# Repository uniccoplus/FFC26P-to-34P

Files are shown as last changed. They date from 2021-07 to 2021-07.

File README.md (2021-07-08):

# FFC26P-to-34P
Replace Matsushita EME-216Y, EME-213K with FDD emulator

This is FFC 26P FDD I/F (Matsushita / Panasonic EME-216Y / EME-213K(KR)) convert to FDD for gotek and HxC2001.

(FFC 26P I/F used to Yamaha VL1 / VL1m / VL7 / KORG N264 / N364, etc)

Matsushita EME-216Y / EME-213K(KR) This is a board that converts the 26Pin FFC signal line of FDD to 34P for gotek and HxC2001.

Since it is still a prototype, it is better to wait for the production to get better results.

Note: We are not responsible for any troubles caused by installing this device. Please pay close attention to the installation and install it carefully.

See the Wiki for details.

ヤマハVL系とコルグN264,N364にFDDエミュレーターを繋ぐための変換基板です。
ぺらぺらのFCCケーブルには5Vが流れており、斜め・逆に挿し間違うと故障しますので充分確認の上作業して下さい。
まだ試作中だから結果が出るまで待った方がいいですよ。
Config等はWikiに上げていきます。

[to Wiki Page](../../wiki)

# Features

Designed to be attached directly to FDD emulator.(HxC for Gotek, Flashfloppy, HxC)

# Requirement

4k7 pull-up resistor 1/6W  x 2

2.54mm 34P(17x2) pin-socket

Molex 52045-2645 26P FFC(or Compatible Connector)

2.54mm Pitch 1x3 pin-header x 2

2.54mm Pitch Jumper Cap x 3

Power Cable(~20cm)

# Making

Solder the resistor, pin header, and connector in that order.

Otherwise, the connector may melt with heat.

The procedure is very important to make it smaller.

順番は抵抗器、ピンヘッダー、コネクターの順に半田付けして下さい。
そうしないとコネクターを熱で溶かしてしまう可能性があります。
より小型にするにはこの手順が非常に重要なのです。

# Usage

For the connection from the main board, the original FFC cable is used as it is.

Insert the metal part (contact) so that it touches the top.

メインボードからの接続は、もとからあるFFCケーブルをそのまま流用します。
金属部分（接点）を必ず上で接触するよう挿し込みます。

# Note

Whether to use DS0 or DS1, HxC's answer is "connect DS0".

But, I chose DS1 because Yamaha uses DS1.

Whether to use 2DD or 2HD, HxC's answer is "nothing connects".

I designed it so that you can choose both.

I don't think anyone makes a mistake in the power line,

but just in case, "Connect a negative line to GND."

DS0とDS1のどちらを使うか、HxCの答えは"DS0を繋ぐ"です。
しかしながらYamahaはDS1を使っているのでDS1を繋ぎました。

2DDと2HDのどちらを使うか、HxCの答えは"何も繋がない"です。
私は両方選択出来るよう設計しました。

GNDはマイナスの意味です。間違う人はいないと思うけど。

# License

This Product is CC BY-NC-SA 4.0

ccbyncsa (https://creativecommons.org/licenses/by-nc-sa/4.0/deed.ja)

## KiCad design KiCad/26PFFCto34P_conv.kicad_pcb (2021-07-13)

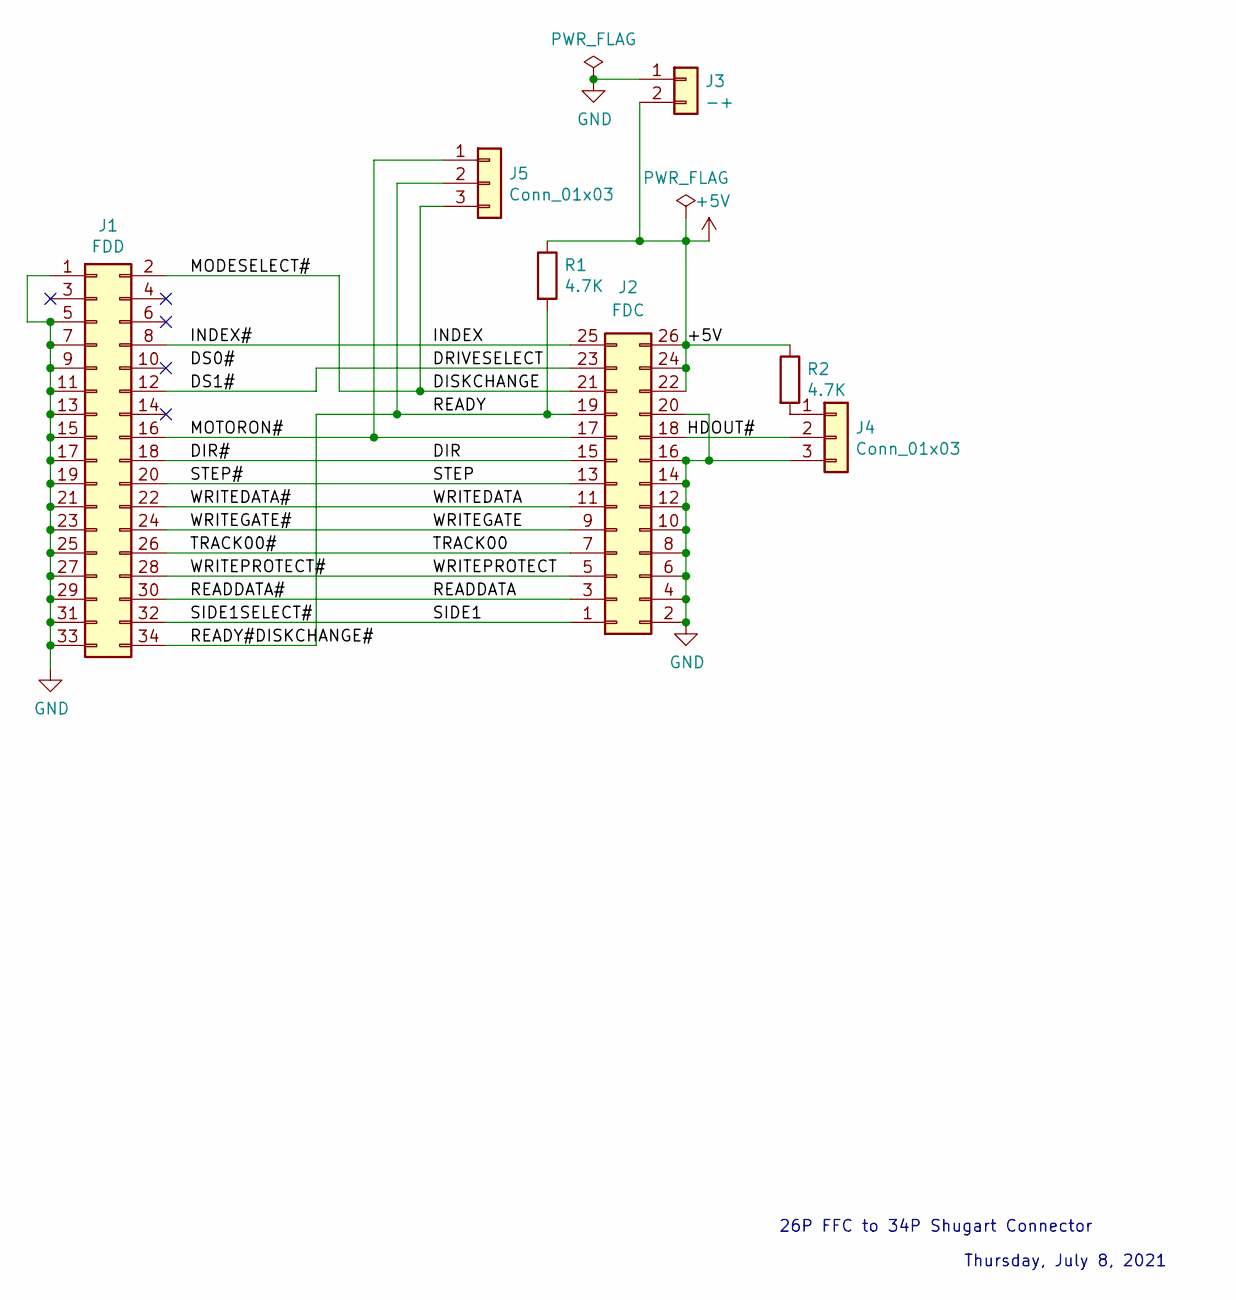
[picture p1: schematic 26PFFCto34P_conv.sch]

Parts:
J1: FDD; PinSocket_2x17_P2.54mm_Vertical
J2: FDC; morex520452645
J3: -+; PinHeader_1x02_P2.54mm_Vertical
J4, J5: Conn_01x03; PinHeader_1x03_P2.54mm_Vertical
R1, R2: 4.7K; R_Axial_DIN0204_L3.6mm_D1.6mm_P5.08mm_Horizontal

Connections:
+5V: J2.22, J2.24, J2.26, J3.2, R1.1, R2.1
/DIR: J1.18, J2.15
/DISKCHANGE: J1.2, J2.21, J5.3
/DRIVESELECT: J1.12, J2.23
/HDOUT#: J2.18, J4.2
/INDEX: J1.8, J2.25
/MOTORON#: J1.16, J2.17, J5.1
/READDATA: J1.30, J2.3
/READY: J1.34, J2.19, J5.2, R1.2
/SIDE1: J1.32, J2.1
/STEP: J1.20, J2.13
/TRACK00: J1.26, J2.7
/WRITEDATA: J1.22, J2.11
/WRITEGATE: J1.24, J2.9
/WRITEPROTECT: J1.28, J2.5
GND: J1.1, J1.5, J1.7, J1.9, J1.11, J1.13, J1.15, J1.17, J1.19, J1.21, J1.23, J1.25, J1.27, J1.29, J1.31, J1.33, J2.2, J2.4, J2.6, J2.8, J2.10, J2.12, J2.14, J2.16, J2.20, J3.1, J4.3
unnamed: J4.1, R2.2

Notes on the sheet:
26P FFC to 34P Shugart Connector
Thursday, July 8, 2021

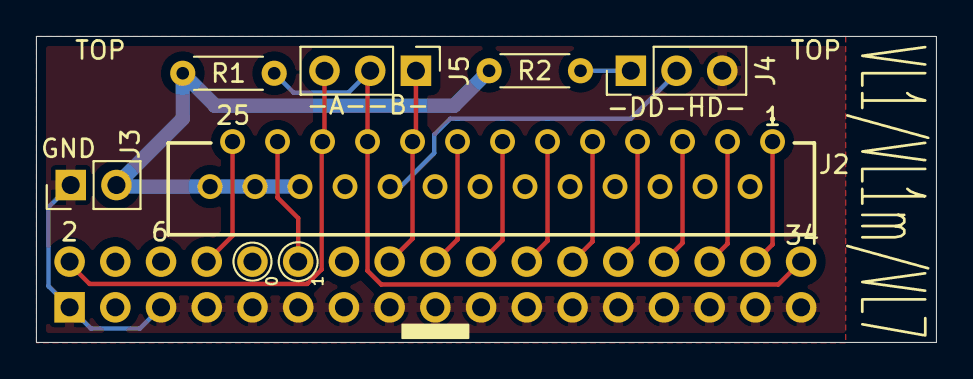
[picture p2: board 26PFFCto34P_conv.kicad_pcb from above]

Board: 2 copper layers, 50.0 x 17.0 mm, 7 parts (1 on the bottom side), 17 nets.

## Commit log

2021-07-08 DS1 fixed. width 48mm to 50mm
    [26PFFCto34P_conv.kicad_pcb, 26PFFCto34P_conv.sch]
2021-07-13 Further miniaturization
    [26PFFCto34P_conv.kicad_pcb, 26PFFCto34P_conv.sch]
